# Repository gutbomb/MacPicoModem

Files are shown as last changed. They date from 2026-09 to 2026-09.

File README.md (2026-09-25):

# Mac Pico Modem

## A Pico W based RS422 \<-\> WiFi modem with Hayes AT style commands and Global Village Teleport style LED indicators

| The Mac Pico modem |

This project is an adaptation of the [mecparts](https://github.com/mecparts)'s 
[Pico WiFi Modem](https://github.com/mecparts/PicoWiFiModem). 

My goal was to make it work with a mac serial port, look the part, and be
cheaper to make.

### First time setup

The default serial configuration is 9600bps, 8 data bits, no parity, 1
stop bit.

Here's the commands you need to set up the modem to automatically
connect to your WiFi network:

1. `AT$SSID=your WiFi network name` to set the WiFi network that the
modem will connect to when it powers up.
2. `AT$PASS=your WiFi network password` to set the password for the
network.
3. `ATC1` to connect to the network.
4. Optional stuff:
   * `AT$SB=speed` to set the default serial speed.
   * `AT$SU=dps` to set the data bits, parity and stop bits.
   * `ATNETn` to select whether or not to use Telnet protocol.
   * `AT&Kn` to use RTS/CTS flow control or not.
   * `AT&Dn` to set up DTR handling.
5. `AT&W` to save the settings.

Once you've done that, the modem will automatically connect to your WiFi
network on power up and will be ready to "dial up" a connection with
ATDT.

### Command Reference

Multiple AT commands can be typed in on a single line. Spaces between
commands are allowed, but not within commands (i.e. AT S0=1 X1 Q0 is
fine; ATS 0=  1 is not). Commands that take a string as an argument
(e.g. AT$SSID=, AT$TTY=) assume that *everything* that follows is a part
of the string, so no commands are allowed after them.

Command | Details
------- | -------
+++     | Online escape code. Once your modem is connected to another device, the only command it recognises is an escape code of a one second pause followed by three typed plus signs and another one second pause, which puts the modem back into local command mode.
A/      | Repeats the last command entered. Do not type AT or press Enter.
AT      | The attention prefix that precedes all command except A/ and +++.
AT?     | Displays a help cheatsheet.
ATA     | Force the modem to answer an incoming connection when the conditions for auto answer have not been satisfied.
ATC?<br>ATC*n* | Query or change the current WiFi connection status. A result of 0 means that the modem is not connected to WiFi, 1 means the modem is connected. The command ATC0 disconnects the modem from a WiFi connection. ATC1 connects the modem to the WiFi.
ATDS*n* | Calls the host specified in speed dial slot *n* (0-9).
ATDT<i>[+=-]host[:port]</i> | Tries to establish a WiFi TCP connection to the specified host name or IP address. If no port number is given, 23 (Telnet) is assumed. You can also use ATDT to dial one of the speed dial slots in one of two ways:<br><br><ul><li>The alias in each speed dial slot is checked to see if it matches the specified hostname.</li><li>A host specified as 7 identical digits dials the slot indicated by the digit. (i.e. 2222222 would speed dial the host in slot 2).</li></ul>Preceding the host name or IP address with a +, = or - character overrides the ATNET setting for the period of the connection.<br><br><ul><li>**+** forces NET2 (fake Telnet)</li><li>**=** forces NET1 (real Telnet)</li><li>**-** forces NET0 (no Telnet)</li></ul>Once the dial attempt has begun, pressing any key before the connection is established will abort the attempt.
ATE?<br>ATE*n* | Command mode echo. Enables or disables the display of your typed commands.<br><br><ul><li>E0 Command mode echo OFF. Your typing will not appear on the screen.</li><li>E1 Command mode echo ON. Your typing will appear on the screen.</li></ul>
ATGET*http&#58;//host[/page]* | Displays the contents of a website page. **https** connections are not supported. Once the contents have been displayed, the connection will automatically terminate.
ATH | Hangs up (ends) the current connection.
ATI | Displays the current network status, including sketch build date, WiFi and call connection state, SSID name, IP address, and bytes transferred.
ATNET?<br>ATNET*n* | Query or change whether telnet protocol is enabled. A result of 0 means that telnet protocol is disabled; 1 is *Real* telnet protocol and 2 is *Fake* telnet protocol. If you are connecting to a telnet server, it may expect the modem to respond to various telnet commands, such as terminal name (set with `AT$TTY`), terminal window size (set with `AT$TTS`) or terminal speed. Telnet protocol should be enabled for these sites, or you will at best see occasional garbage characters on your screen, or at worst the connection may fail.<br><br>The difference between *real* and *fake* telnet protocol is this: with *real* telnet protocol, a carriage return (CR) character being sent from the modem to the telnet server always has a NUL character added after it. The implementation of the telnet protocol used by some BBSes doesn't properly strip out the NUL character. When connecting to such BBSes (Particles! is one), use *fake* telnet.<br><br>When using *real* telnet protocol, when the telnet server sends a CR character followed by a NUL character, only the CR character will be sent to the serial port; the NUL character will be silently stripped out. With *fake* telnet protocol, the NUL will be passed through.
ATO | Return online. Use with the escape code (+++) to toggle between command and online modes.
ATQ?<br>ATQ*n* | Enable or disable the display of result codes. The default is Q0.<br><br><ul><li>Q0 Display result codes.</li><li>Q1 Suppress result codes (quiet).</li></ul>
ATRD<br>ATRT | Displays the current UTC date and time from NIST in the format *YY-MM-DD HH:MM:SS*. A WiFi connection is required and you cannot be connected to another site.
ATS0?<br>ATS0=*n* | Display or set the number of "rings" before answering an incoming connection. Setting `S0=0` means "don't answer".
ATS2?<br>ATS2=*n* | Display or set the ASCII code used in the online escape sequence. The default value is 43 (the + plus character). Setting it to any value between 128 and 255 will disable the online escape function.
ATV?<br>ATV*n* | Display result codes in words or numbers. The default is V1.<br><br><ul><li>V0 Display result codes in numeric form.</li><li>V1 Display result codes in text form.</li></ul>
ATX?<br>ATX*n* | Control the amount of information displayed in the result codes. The default is X1 (extended codes).<br><br><ul><li>X0 Display basic codes (CONNECT, NO CARRIER)</li><li>X1 Display extended codes (CONNECT speed, NO CARRIER (connect time))</li></ul>
ATZ | Resets the modem.
AT&D?<br>AT&D*n* | Display or set the handling of DTR going inactive. The default is &D0 (ignored).<br><br><ul><li>&D0 Ignore</li><li>&D1 Go to command mode</li><li>&D2 End call</li><li>&D3 Reset modem</li></ul>
AT&F | Reset the NVRAM contents and current settings to the sketch defaults. All settings, including SSID name, password and speed dial slots are affected.
AT&K?<br>AT&K*n* | Data flow control. Prevents the modem's buffers for received and transmitted from overflowing.<br><br><ul><li>&K0 Disable data flow control.</li><li>&K1 Use hardware flow control. Requires that your computer and software support Clear to Send (CTS) and Request to Send (RTS) at the RS-232 interface.</li></ul>
AT&R?<br>AT&R=*server pwd* | Query or change the password for incoming connections. If set, the user has 3 chances in 60 seconds to enter the correct password or the modem will end the connection.
AT&V*n* | Display current or stored settings.<br><br><ul><li>&V0 Display current settings.</li><li>&V1 Display stored settings.</li></ul>
AT&W | Save current settings to NVRAM.
AT&Zn?<br>AT&Z*n*=*host[:port],alias* | Store up to 10 numbers in NVRAM, where *n* is the position 0-9 in NVRAM, and *host[:port]* is the host string, and *alias* is the speed dial alias name. The host string may be up to 50 characters long, and the alias string may be up to 16 characters long.<br><br>Example: `AT&Z2=particlesbbs.dyndns.org:6400,particles`<br><br>This number can then be dialed in any of the following ways:<br><br><ul><li>`ATDS2`</li><li>`ATDTparticles`</li><li>`ATDT2222222`</li></ul>
AT$AE?<br>AT$AE=*startup AT cmd* | Query or change the command line to be executed when the modem starts up.
AT$AYT | Sends a Telnet "Are You There?" command if connected to a Telnet remote.
AT$BM?<br>AT$BM=*server busy msg* | Query or change a message to be returned to an incoming connection if the modem is busy (i.e. already has a connection established).
AT$MDNS<br>AT$MDNS=*mDNS name* | Query or change the mDNS network name (defaults to "espmodem"). When a non zero TCP port is defined, you can telnet to that port with **telnet mdnsname.local port**.
AT$PASS?<br>AT$PASS=*WiFi pwd* | Query or change the current WiFi password. The password is case sensitive. Clear the password by issuing the set command with no password. The maximum length of the password is 64 characters.
AT$SB?<br>AT$SB=*n* | Query or change the current baud rate. Valid values for "n" are 110, 300, 450, 600, 710, 1200, 2400, 4800, 9600, 19200, 38400, 57600, 76800 and 115200. Any other value will return an ERROR message. The default baud rate is 1200. The Pico WiFi modem does not automatically detect baud rate like a dial-up modem. The baud rate setting must match that of your terminal to operate properly. It will display garbage in your terminal otherwise.
AT$SP?<br>AT$SP=*n* | TCP server port to listen on. A value of 0 means that the TCP server is disabled, and no incoming connections are allowed.
AT$SSID?<br>AT$SSID=*ssid name* | Query or change the current SSID to the specified name. The given SSID name is case sensitive. Clear the SSID by issuing the set command with no SSID. The maximum length of the SSID name is 32 characters.
AT$SU?<br>AT$SU=*dps* | Query or change the current number of data bits ('d'), parity ('p') and stop bits ('s") of the serial UART. Valid values for 'd' are 5, 6, 7 or 8 bits. Valid values for 'p' are (N)one, (O)dd or (E)ven parity. Valid values for 's' are 1 or 2 bits. The default settings are 8N1. The UART setting must match your terminal to work properly.
AT$TTL?<br>AT$TTL=*telnet location* | Query or change the Telnet location value to be returned when the Telnet server issues a SEND-LOCATION request. The default value is "Computer Room".
AT$TTS?<br>AT$TTS=*WxH* | Query or change the window size (columns x rows) to be returned when the Telnet server issues a NAWS (Negotiate About Window Size) request. The default value is 80x24. For terminals that are smaller than 80x24, setting these values appropriately will enable paging on the help (AT?) and network status (ATI) commands.
AT$TTY?<br>AT$TTY=*terminal type* | Query or change the terminal type to be returned when the Telnet server issues a TERMINAL-TYPE request. The default value is "ansi".
AT$W?<br>AT$W=*n* | Startup wait.<br><br><ul><li>$W=0 Startup with no wait.</li><li>$W=1 Wait for the return key to be pressed at startup.</li></ul>

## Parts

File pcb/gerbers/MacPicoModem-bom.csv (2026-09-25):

Id | Designator | Footprint | Quantity | Designation | Supplier and ref
1 | C1, C2, C3, C4, C5, C6, C7 | C_0805_2012Metric | 7 | 100nF
2 | D1, D2, D3 | LED0805-R-RD | 3 | FC-2012UGK-520D5
3 | J1 | CONN-TH_DIN-802 | 1 | DIN-802
4 | J2 | USB-C-SMD_TYPE-C-16PIN-2MD-073 | 1 | TYPE-C 16PIN 2MD
5 | R1, R2, R3 | R_0805_2012Metric | 3 | 560R
6 | R4, R5 | R_0805_2012Metric | 2 | 3.9K
7 | R6, R7 | R0805 | 2 | 0805W8F5101T5E
8 | SW1 | KEY-TH_K2-1102AQ-JXXW-XX | 1 | K2-1102AQ-J4CW-01
9 | U1 | SSOP-28_L10.2-W5.3-P0.65-LS7.8-BL | 1 | SP3238EEA-L/TR
10 | U2 | TSSOP-20_L6.5-W4.4-P0.65-LS6.4-BL | 1 | 74HCT245
11 | U3 | RaspberryPi_Pico_W_SMD | 1 | Pico
12 | U4 | SOIC-8_L4.9-W3.9-P1.27-LS6.0-BL | 1 | 24LC32A-I/SN

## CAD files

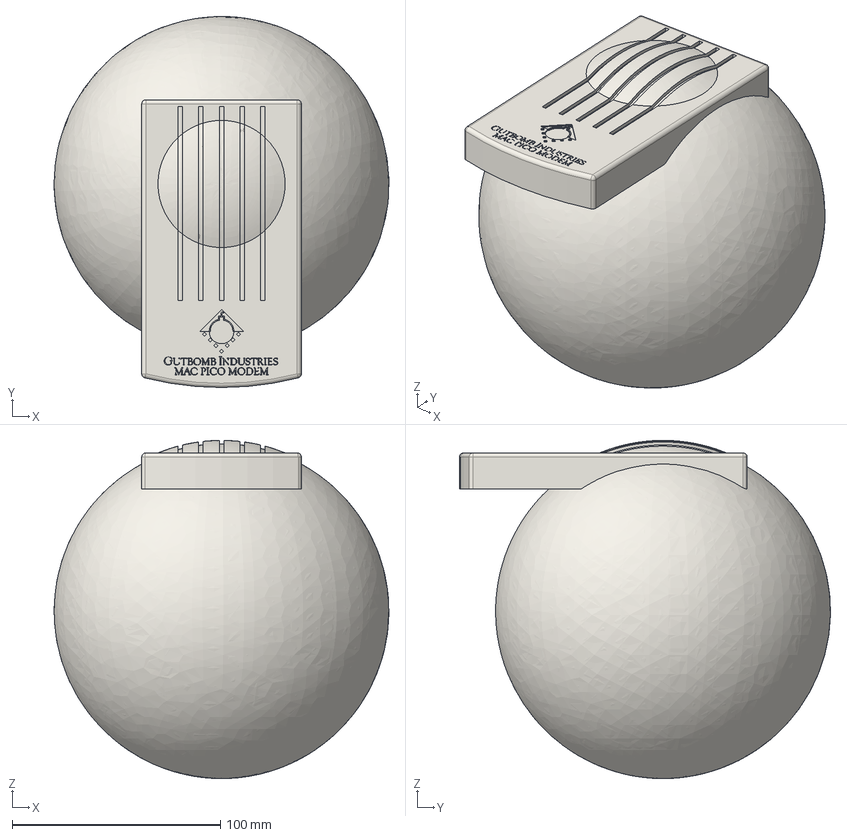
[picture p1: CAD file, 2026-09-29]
enclosure/MacPicoModem enclosure-Top with speaker hump.step
160.6 x 178.0 x 162.2 mm

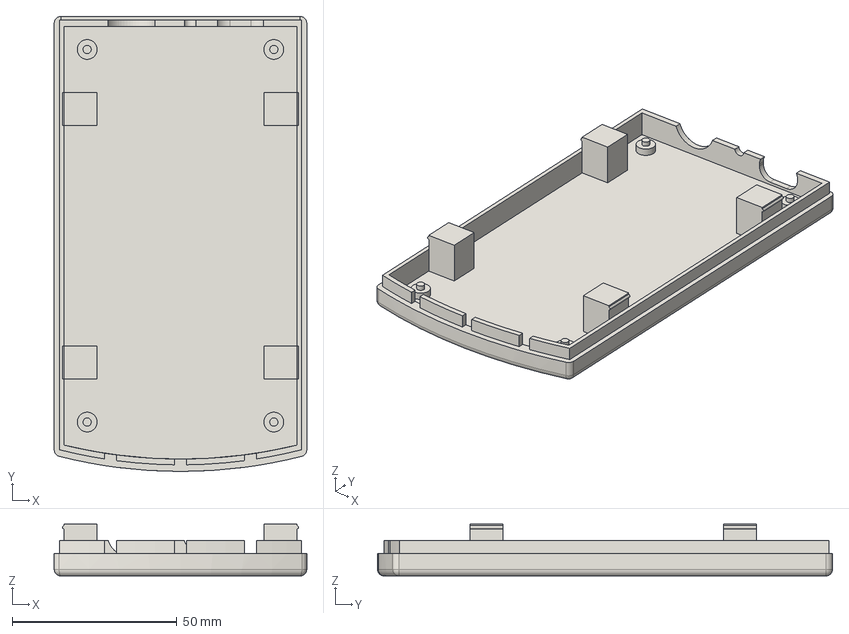
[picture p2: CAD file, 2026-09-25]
enclosure/MacPicoModem enclosure-Bottom.step
76.6 x 138.0 x 15.8 mm

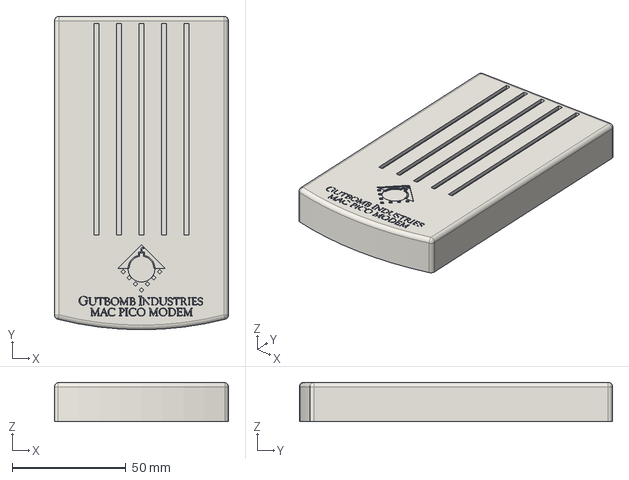
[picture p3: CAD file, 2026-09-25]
enclosure/MacPicoModem enclosure-Top.step
76.6 x 138.0 x 17.2 mm

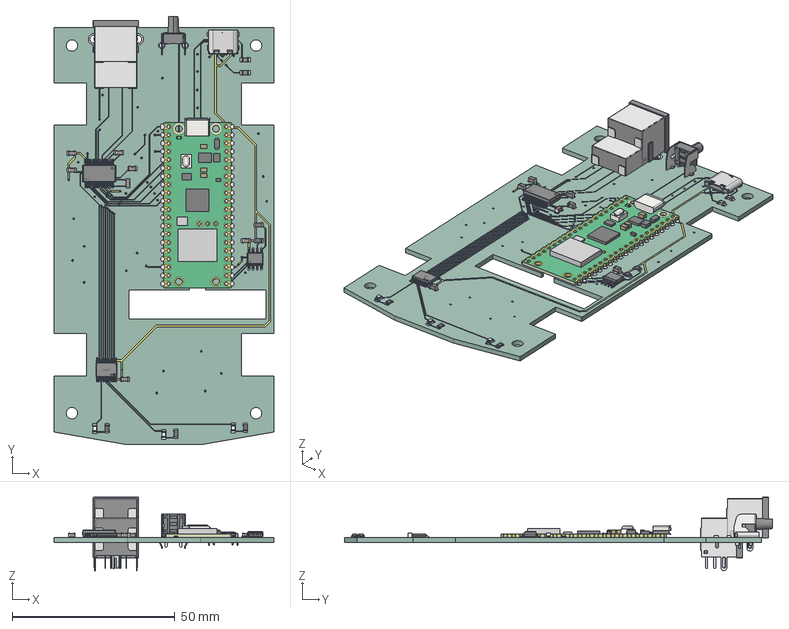
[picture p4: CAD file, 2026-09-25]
enclosure/pcb.step
67.6 x 131.7 x 22.6 mm
C_0805_2012Metric x 7
CONN-TH_DIN-802 x 2
R_0805_2012Metric x 5
LED0805-RD x 3
零件3
KEY-TH_4P-L7.4-W8.5-H7.1-LS7.0-P4.5
R0805_L2.0-W1.3-H0.6 x 2
RaspberryPi_Pico_W_Module_KiCad
TSSOP-20_L6.5-W4.4-H1.0-LS6.4-P0.65
SOIC-8_L4.9-W3.9-H1.7-LS6.0-P1.27
USB-C-SMD_TYPE-C-6PIN-2MD-073
MacPicoModem_copper
MacPicoModem_pad
MacPicoModem_via
MacPicoModem_PCB

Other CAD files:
enclosure/MacPicoModem enclosure.FCStd
enclosure/MacPicoModem enclosure-Bottom.stl
enclosure/MacPicoModem enclosure-Top with speaker hump.stl
enclosure/MacPicoModem enclosure-Top.stl

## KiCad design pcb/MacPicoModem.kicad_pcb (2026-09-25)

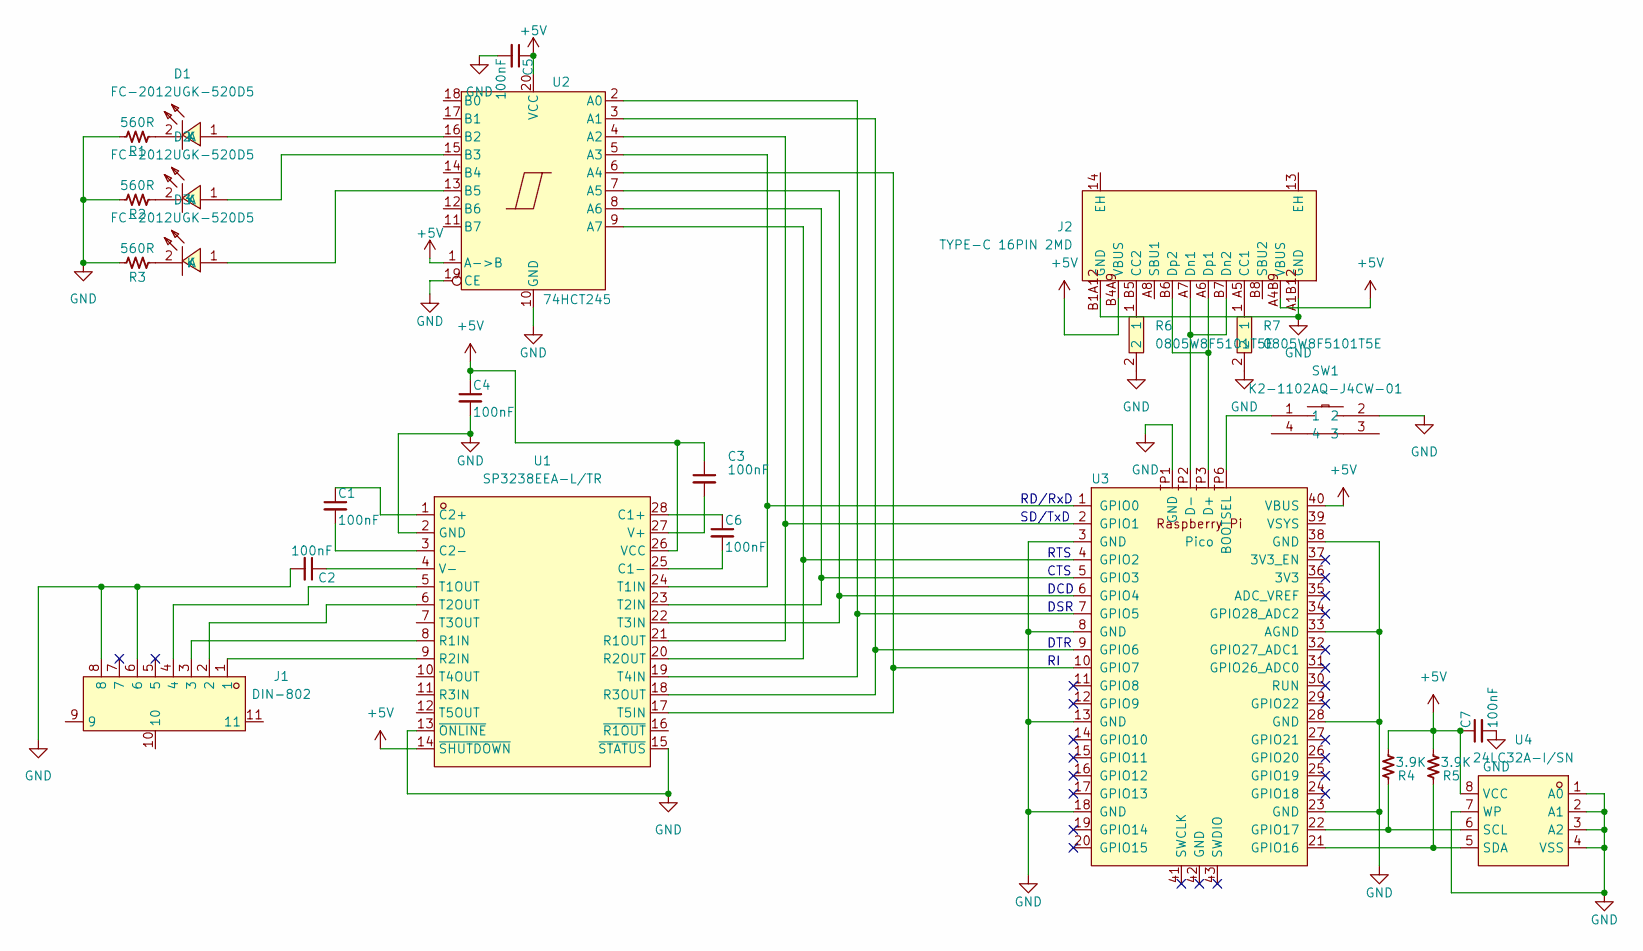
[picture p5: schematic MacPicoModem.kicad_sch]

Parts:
C1, C2, C3, C4, C5: 100nF; C_0805_2012Metric; DigiKey PN 399-9859-1-ND
C6, C7: 100nF; C_0805_2012Metric; DigiKey PN 399-9843-ND
D1, D2, D3: FC-2012UGK-520D5; LED0805-R-RD; MPN NCD0805G1; LCSC Part C84260
J1: DIN-802; CONN-TH_DIN-802; MPN DIN-802; LCSC Part C20611694
J2: TYPE-C 16PIN 2MD; USB-C-SMD_TYPE-C-16PIN-2MD-073; MPN TYPE-C 16PIN 2MD(073); LCSC Part C2765186
R1, R2, R3: 560R; R_0805_2012Metric; DigiKey PN CF18JT560RCT-ND
R4, R5: 3.9K; R_0805_2012Metric; LCSC Part C2907252
R6, R7: 0805W8F5101T5E; R0805; MPN 0805W8F5101T5E; LCSC Part C27834
SW1: K2-1102AQ-J4CW-01; KEY-TH_K2-1102AQ-JXXW-XX; MPN K2-1102AQ-J4CW-01; LCSC Part C136735
U1: SP3238EEA-L/TR; SSOP-28_L10.2-W5.3-P0.65-LS7.8-BL; MPN SP3238EEA-L/TR; LCSC Part C49669
U2: 74HCT245; TSSOP-20_L6.5-W4.4-P0.65-LS6.4-BL; LCSC Part C52140501
U3: Pico; RaspberryPi_Pico_W_SMD
U4: 24LC32A-I/SN; SOIC-8_L4.9-W3.9-P1.27-LS6.0-BL; MPN 24LC32A-I/SN; LCSC Part C511262

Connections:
+5V: C3.1, C4.1, C5.1, C7.1, J2.A4B9 (VBUS), J2.B4A9 (VBUS), R4.1, R5.1, U1.14 (~SHUTDOWN), U1.26 (VCC), U2.1 (A->B), U2.20 (VCC), U3.40 (VBUS), U4.8 (VCC)
GND: C2.2, C4.2, C5.2, C7.2, J1.6, J1.8, J2.A1B12 (GND), J2.B1A12 (GND), R1.2, R2.2, R3.2, R6.2, R7.2, SW1.2, U1.2 (GND), U1.13 (~ONLINE), U1.15 (~STATUS), U2.10 (GND), U2.19 (CE), U3.3 (GND), U3.8 (GND), U3.13 (GND), U3.18 (GND), U3.23 (GND), U3.28 (GND), U3.33 (AGND), U3.38 (GND), U3.TP1 (GND), U4.1 (A0), U4.2 (A1), U4.3 (A2), U4.4 (VSS), U4.7 (WP)
unnamed: D1.1 (A), U2.16 (B2)
unnamed: D1.2 (K), R1.1
unnamed: D2.1 (A), U2.15 (B3)
unnamed: D2.2 (K), R2.1
unnamed: D3.1 (A), U2.13 (B5)
unnamed: D3.2 (K), R3.1
unnamed: J2.A5 (CC1), R7.1
unnamed: J2.B5 (CC2), R6.1
unnamed: J2.A7 (Dn1), J2.B7 (Dn2), U3.TP2 (D-)
unnamed: J2.A6 (Dp1), J2.B6 (Dp2), U3.TP3 (D+)
unnamed: C6.1, U1.28 (C1+)
unnamed: C6.2, U1.25 (C1-)
unnamed: C1.1, U1.1 (C2+)
unnamed: C1.2, U1.3 (C2-)
unnamed: J1.3, U1.8 (R1IN)
unnamed: U1.21 (R1OUT), U2.4 (A2), U3.2 (GPIO1)
unnamed: J1.1, U1.9 (R2IN)
unnamed: U1.20 (R2OUT), U2.9 (A7), U3.4 (GPIO2)
unnamed: U1.18 (R3OUT), U2.3 (A1), U3.9 (GPIO6)
unnamed: U1.24 (T1IN), U2.5 (A3), U3.1 (GPIO0)
unnamed: J1.4, U1.5 (T1OUT)
unnamed: U1.23 (T2IN), U2.8 (A6), U3.5 (GPIO3)
unnamed: J1.2, U1.6 (T2OUT)
unnamed: U1.22 (T3IN), U2.7 (A5), U3.6 (GPIO4)
unnamed: U1.19 (T4IN), U2.2 (A0), U3.7 (GPIO5)
unnamed: U1.17 (T5IN), U2.6 (A4), U3.10 (GPIO7)
unnamed: C3.2, U1.27 (V+)
unnamed: C2.1, U1.4 (V-)
unnamed: SW1.1, U3.TP6 (BOOTSEL)
unnamed: R5.2, U3.21 (GPIO16), U4.5 (SDA)
unnamed: R4.2, U3.22 (GPIO17), U4.6 (SCL)

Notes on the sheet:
DTR
RD/RxD
DSR
DCD
RTS
SD/TxD
CTS

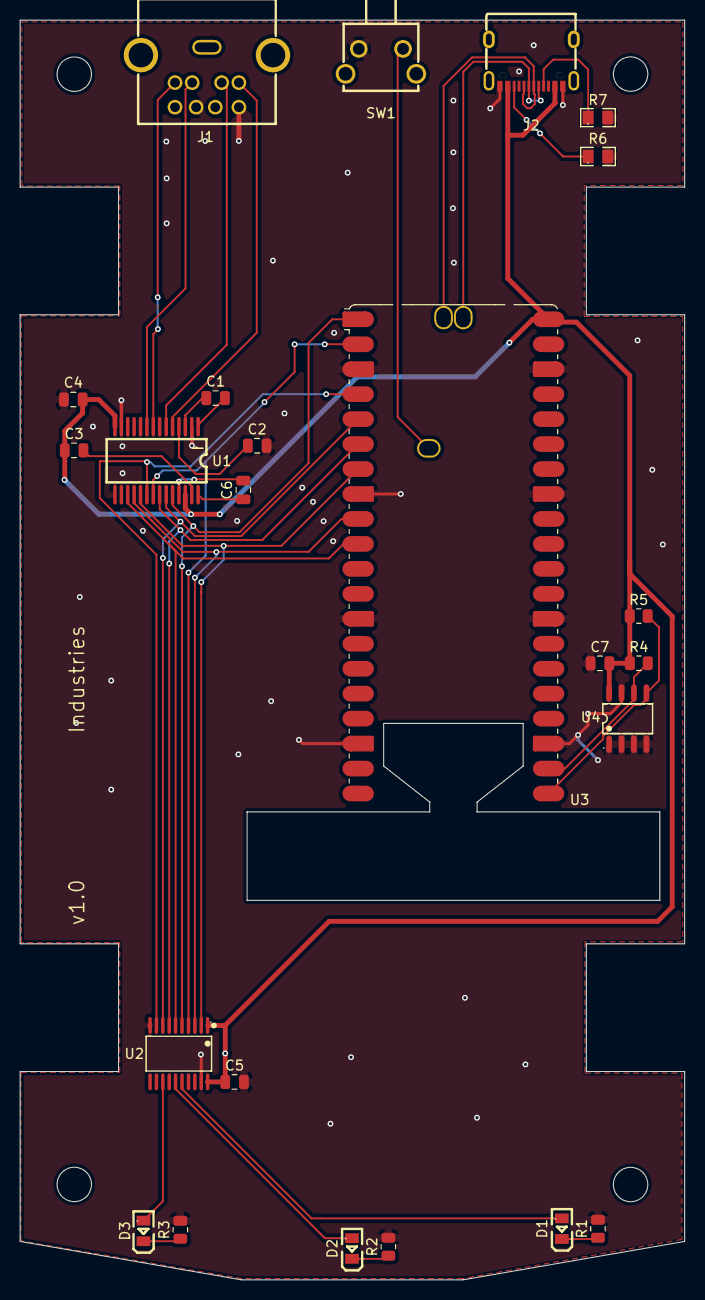
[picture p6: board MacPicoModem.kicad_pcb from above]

Board: 2 copper layers, 67.6 x 128.2 mm, 24 parts (0 on the bottom side), 33 nets.

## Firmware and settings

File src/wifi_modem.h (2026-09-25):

#ifndef _MODEM_H
   #define _MODEM_H

   #define DEBUG                 0
   #define DEFAULT_SPEED         9600

   #define RING_INTERVAL         1500
   #define MAX_CMD_LEN           256
   #define TX_BUF_SIZE           256
   #define ESC_CHAR              '+'
   #define ESC_COUNT             3
   #define GUARD_TIME            1000
   #define MAGIC_NUMBER          0x5678
   #define MAX_SSID_LEN          32
   #define MAX_WIFI_PWD_LEN      64
   #define DEFAULT_LISTEN_PORT   6400
   #define TELNET_PORT           23
   #define HTTP_PORT             80
   #define SPEED_DIAL_SLOTS      10
   #define MAGIC_ANSWER_RINGS    3
   #define MAX_ALIAS_LEN         16
   #define MAX_SPEED_DIAL_LEN    50
   #define MAGIC_SPEED_LEN       7
   #define MAX_MDNSNAME_LEN      80
   #define MAX_BUSYMSG_LEN       80
   #define MAX_PWD_LEN           80
   #define PASSWORD_TIME         60000
   #define PASSWORD_TRIES        3
   #define MAX_AUTOEXEC_LEN      80
   #define MAX_TERMINAL_LEN      80
   #define MAX_LOCATION_LEN      80

   #define NUL  '\x00'
   #define CTLC '\x03'
   #define BS   '\x08'
   #define LF   '\x0A'
   #define CR   '\x0D'
   #define DEL  '\x7F'

   #define NO_TELNET   ((uint8_t)0)
   #define REAL_TELNET ((uint8_t)1)
   #define FAKE_TELNET ((uint8_t)2)

   // Telnet codes
   #define VLSUP     ((uint8_t)0)
   #define VLREQ     ((uint8_t)1)
   #define LOC       ((uint8_t)23)
   #define TTYPE     ((uint8_t)24)
   #define NAWS      ((uint8_t)31)
   #define TSPEED    ((uint8_t)32)
   #define LFLOW     ((uint8_t)33)
   #define LINEMODE  ((uint8_t)34)
   #define XDISPLOC  ((uint8_t)35)
   #define NEW_ENVIRON ((uint8_t)39)
   #define BINARY    ((uint8_t)0)
   #define ECHO      ((uint8_t)1)
   #define SUP_GA    ((uint8_t)3)
   #define SE        ((uint8_t)240)
   #define DM        ((uint8_t)242)
   #define BRK       ((uint8_t)243)
   #define AYT       ((uint8_t)246)
   #define SB        ((uint8_t)250)
   #define WILL      ((uint8_t)251)
   #define WONT      ((uint8_t)252)
   #define DO        ((uint8_t)253)
   #define DONT      ((uint8_t)254)
   #define IAC       ((uint8_t)255)

   #define NIST_HOST "time.nist.gov"
   #define NIST_PORT 13

   #define ACTIVE LOW           // RS232 control signals are active low

   #define RTS  2           // (GPIO02) input
   #define CTS  3           // (GPIO03) output
   #define DCD  4           // (GPIO04) output
   #define DSR  5           // (GPIO05) output
   #define DTR  6           // (GPIO06) input
   #define RI   7           // (GPIO07) output
   
   #define OUTPUT true
   #define INPUT  false
   #define HIGH   true
   #define LOW    false

   // I2C EEPROM definitions
   #define I2C_ADDR  0x50
   #define I2C_SDA   16
   #define I2C_SCL   17
   #define I2C_BAUD  100000
   
   #define TCP_CLIENT_RX_BUF_SIZE 20000
   #define TCP_CLIENT_TX_BUF_SIZE 1100
   
#ifndef NDEBUG
   #define POLL_STATE_LED 8
   #define RXBUFF_OVFL 9
   #define TXBUFF_OVFL 10
#endif

#endif

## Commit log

2026-07-22 first pcb and case
    [MacPicoModem enclosure-Bottom.step, MacPicoModem enclosure-Bottom.stl, MacPicoModem enclosure-Top.step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]
2026-09-29 added a speaker hump version
    [MacPicoModem enclosure-Top with speaker hump.step]
2026-09-29 forgot the stl for the speaker hump version
    [MacPicoModem enclosure-Top with speaker hump.stl]
